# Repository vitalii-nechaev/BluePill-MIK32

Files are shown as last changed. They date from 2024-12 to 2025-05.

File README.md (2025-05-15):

# BluePill-MIK32
Проект отладочной платы MIK32 АМУР К1948ВК018, выполненный в среде KiCad.   
В папке КД находятся pdf-файлы документации на плату. Текстовые документы сгенерированы в программе [ДокГОСТ](https://github.com/vitalii-nechaev/DocGOST).  
Подробнее с проектом можно ознакомиться на [странице проекта](http://xn-----6kccalfmhwcdcrbm1aajnghfrqjce3b0z.xn--p1ai/MCU/MIK32_devboard.html).

BluePill-MIK32

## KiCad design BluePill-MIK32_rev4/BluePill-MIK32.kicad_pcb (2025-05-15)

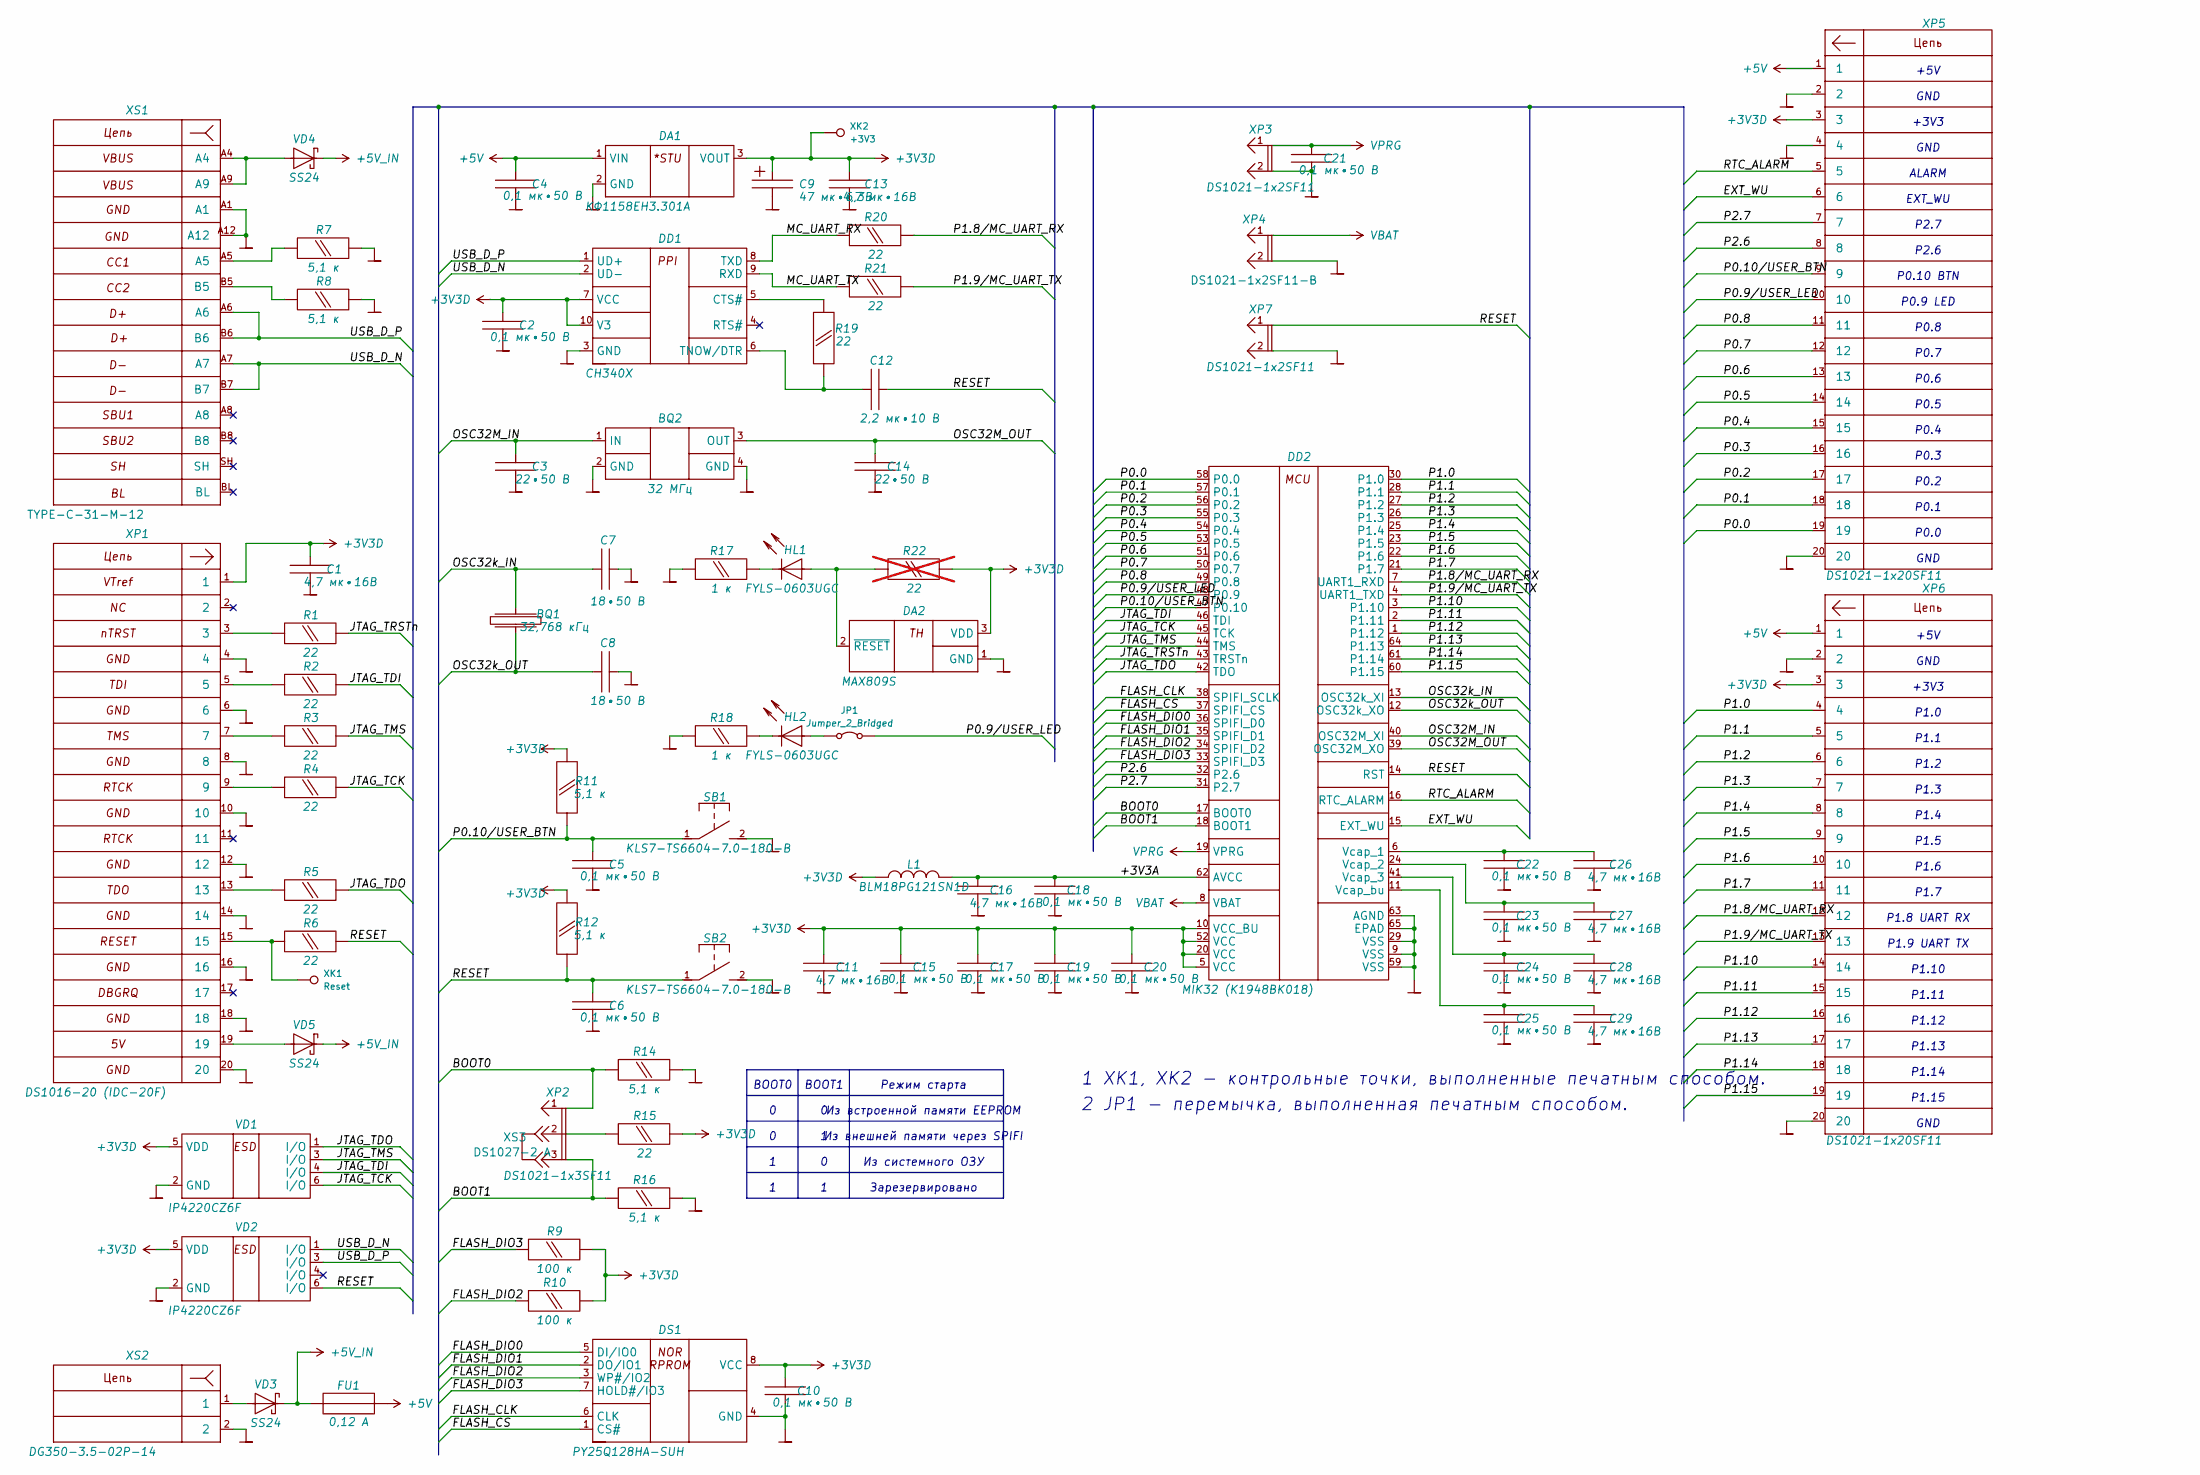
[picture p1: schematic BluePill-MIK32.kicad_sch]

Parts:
BQ1: 32,768 кГц; Crystal_SMD_3215-2Pin_3.2x1.5mm; PartNumber X321532768KGD2SI
BQ2: 32 МГц; Crystal_SMD_3225-4Pin_3.2x2.5mm; PartNumber X322532MOB4SI
C1, C11, C13, C16, C26, C27, C28, C29: 4,7 мк•16В; C_0603_1608Metric; PartNumber GRM188R61C475KE11D
C2, C4, C5, C6, C10, C15, C17, C18, C19, C20, C21, C22, C23, C24, C25: 0,1 мк•50 В; C_0402_1005Metric; PartNumber GRM155R71H104KE14D
C3, C14: 22•50 В; C_0402_1005Metric; PartNumber GRM1555C1H220JA01D
C7, C8: 18•50 В; C_0402_1005Metric; PartNumber GRM1555C1E180JA01D
C9: 47 мк•6,3В; CP_Radial_D5mm_P2.5mm_H11mm; PartNumber К50-68-6,3В-47мкФ±20%
C12: 2,2 мк•10 В; C_0402_1005Metric; PartNumber GRM155R61A225KE01D
DA1: КФ1158ЕН3.301А; TO-252-2; PartNumber КФ1158ЕН3.301А
DA2: MAX809S; SOT-23; PartNumber MAX809S
DD1: CH340X; MSOP-10_3x3mm_P0.5mm; PartNumber CH340X
DD2: MIK32 (К1948ВК018); QFN-64-1EP_8x8mm_P0.4mm_EP6.5x6.5mm; PartNumber К1948ВК018
DS1: PY25Q128HA-SUH; SOIC-8_5.23x5.23mm_P1.27mm; PartNumber PY25Q128HA-SUH
FU1: 0,12 А; Fuse_1206_3216Metric; PartNumber FSMD012-1206-R
HL1, HL2: FYLS-0603UGC; LED_0603_1608Metric; PartNumber FYLS-0603UGC
JP1: Jumper_2_Bridged; SolderJumper-2_P1.3mm_Bridged_RoundedPad1.0x1.5mm
L1: BLM18PG121SN1D; L_0603_1608Metric; PartNumber BLM18PG121SN1D
R1, R2, R3, R4, R5, R6, R15, R19, R20, R21: 22; R_0603_1608Metric; PartNumber RC0603JR-0722RL
R7, R8, R11, R12, R14, R16: 5,1 к; R_0603_1608Metric; PartNumber RC0603FR-075K1L
R9, R10: 100 к; R_0603_1608Metric; PartNumber RC0603JR-07100KL
R17, R18: 1 к; R_0603_1608Metric; PartNumber RC0603JR-071KL
R22: 22; R_0603_1608Metric; PartNumber RC0603JR-0722RL; not fitted
SB1, SB2: KLS7-TS6604-7.0-180-B; SW_Push_1P1T_NO_6x6mm_H9.5mm; PartNumber KLS7-TS6604-7.0-180-B
VD1, VD2: IP4220CZ6F; SOT-23-6; PartNumber IP4220CZ6
VD3, VD4, VD5: SS24; DO-214AC(SMA); PartNumber SS24
XK1: Reset; TestPoint_THTPad_D2.0mm_Drill1.0mm
XK2: +3V3; TestPoint_THTPad_D2.0mm_Drill1.0mm
XP1: DS1016-20 (IDC-20F); IDC-Header_2x10_P2.54mm_Vertical; PartNumber DS1016-20 (IDC-20F)
XP2: DS1021-1x3SF11; PinHeader_1x03_P2.54mm_Vertical; PartNumber DS1021-1x3SF11
XP3, XP7: DS1021-1x2SF11; PinHeader_1x02_P2.54mm_Vertical; PartNumber DS1021-1x2SF11
XP4: DS1021-1x2SF11-B; PinHeader_1x02_P2.54mm_Vertical; PartNumber DS1021-1x2SF11-B
XP5, XP6: DS1021-1x20SF11; PinHeader_1x20_P2.54mm_Vertical; PartNumber DS1021-1x20SF11
XS1: TYPE-C-31-M-12; USB_C_Receptacle_16P_TopMnt_Horizontal; PartNumber TYPE-C-31-M-12
XS2: DG350-3.5-02P-14; TerminalBlock_1x02_P3.50mm_Horizontal; PartNumber DG350-3.5-02P-14
XS3: DS1027-2 A; PartNumber DS1027-2 A

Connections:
+3V3D: C1.1, C2.1, C9.1, C10.1, C11.1, C13.1, C15.1, C17.1, C19.1, C20.1, DA1.3 (VOUT), DA2.3 (VDD), DD1.7 (VCC), DD1.10 (V3), DD2.5 (VCC), DD2.10 (VCC_BU), DD2.20 (VCC), DD2.52 (VCC), DS1.8 (VCC), L1.1, R9.2, R10.2, R11.2, R12.2, R15.2, R22.2, VD1.5 (VDD), VD2.5 (VDD), XK2.1, XP1.1, XP5.3, XP6.3
+5V: C4.1, DA1.1 (VIN), FU1.2, XP5.1, XP6.1
+5V_IN: FU1.1, VD3.1 (K), VD4.1 (K), VD5.1 (K)
/+3V3A: C16.1, C18.1, DD2.62 (AVCC), L1.2
/BOOT0: DD2.17 (BOOT0), R14.1, XP2.1
/BOOT1: DD2.18 (BOOT1), R16.1, XP2.3
/EXT_WU: DD2.15 (EXT_WU), XP5.6
/FLASH_CLK: DD2.38 (SPIFI_SCLK), DS1.6 (CLK)
/FLASH_CS: DD2.37 (SPIFI_CS), DS1.1 (CS#)
/FLASH_DIO0: DD2.36 (SPIFI_D0), DS1.5 (DI/IO0)
/FLASH_DIO1: DD2.35 (SPIFI_D1), DS1.2 (DO/IO1)
/FLASH_DIO2: DD2.34 (SPIFI_D2), DS1.3 (WP#/IO2), R10.1
/FLASH_DIO3: DD2.33 (SPIFI_D3), DS1.7 (HOLD#/IO3), R9.1
/JTAG_TCK: DD2.45 (TCK), R4.2, VD1.6 (I/O)
/JTAG_TDI: DD2.46 (TDI), R2.2, VD1.4 (I/O)
/JTAG_TDO: DD2.42 (TDO), R5.2, VD1.1 (I/O)
/JTAG_TMS: DD2.44 (TMS), R3.2, VD1.3 (I/O)
/JTAG_TRSTn: DD2.43 (TRSTn), R1.2
/MC_UART_RX: DD1.8 (TXD), R20.1
/MC_UART_TX: DD1.9 (RXD), R21.1
/OSC32M_IN: BQ2.1 (IN), C3.1, DD2.40 (OSC32M_XI)
/OSC32M_OUT: BQ2.3 (OUT), C14.1, DD2.39 (OSC32M_XO)
/OSC32k_IN: BQ1.2, C7.1, DD2.13 (OSC32k_XI)
/OSC32k_OUT: BQ1.1, C8.1, DD2.12 (OSC32k_XO)
/P0.0: DD2.58 (P0.0), XP5.19
/P0.1: DD2.57 (P0.1), XP5.18
/P0.2: DD2.56 (P0.2), XP5.17
/P0.3: DD2.55 (P0.3), XP5.16
/P0.4: DD2.54 (P0.4), XP5.15
/P0.5: DD2.53 (P0.5), XP5.14
/P0.6: DD2.51 (P0.6), XP5.13
/P0.7: DD2.50 (P0.7), XP5.12
/P0.8: DD2.49 (P0.8), XP5.11
/P0.9/USER_LED: DD2.48 (P0.9), JP1.2 (B), XP5.10
/P0.10/USER_BTN: C5.1, DD2.47 (P0.10), R11.1, SB1.1, XP5.9
/P1.0: DD2.30 (P1.0), XP6.4
/P1.1: DD2.28 (P1.1), XP6.5
/P1.2: DD2.27 (P1.2), XP6.6
/P1.3: DD2.26 (P1.3), XP6.7
/P1.4: DD2.25 (P1.4), XP6.8
/P1.5: DD2.23 (P1.5), XP6.9
/P1.6: DD2.22 (P1.6), XP6.10
/P1.7: DD2.21 (P1.7), XP6.11
/P1.8/MC_UART_RX: DD2.7 (UART1_RXD), R20.2, XP6.12
/P1.9/MC_UART_TX: DD2.4 (UART1_TXD), R21.2, XP6.13
/P1.10: DD2.3 (P1.10), XP6.14
/P1.11: DD2.2 (P1.11), XP6.15
/P1.12: DD2.1 (P1.12), XP6.16
/P1.13: DD2.64 (P1.13), XP6.17
/P1.14: DD2.61 (P1.14), XP6.18
/P1.15: DD2.60 (P1.15), XP6.19
/P2.6: DD2.32 (P2.6), XP5.8
/P2.7: DD2.31 (P2.7), XP5.7
/RESET: C6.1, C12.2, DD2.14 (RST), R6.2, R12.1, SB2.1, VD2.6 (I/O), XP7.1
/RTC_ALARM: DD2.16 (RTC_ALARM), XP5.5
/USB_D_N: DD1.2 (UD-), VD2.1 (I/O), XS1.A7, XS1.B7
/USB_D_P: DD1.1 (UD+), VD2.3 (I/O), XS1.A6, XS1.B6
GND: BQ2.2 (GND), BQ2.4 (GND), C1.2, C2.2, C3.2, C4.2, C5.2, C6.2, C7.2, C8.2, C9.2, C10.2, C11.2, C13.2, C14.2, C15.2, C16.2, C17.2, C18.2, C19.2, C20.2, C21.2, C22.2, C23.2, C24.2, C25.2, C26.2, C27.2, C28.2, C29.2, DA1.2 (GND), DA2.1 (GND), DD1.3 (GND), DD2.9 (VSS), DD2.29 (VSS), DD2.59 (VSS), DD2.63 (AGND), DD2.65 (EPAD), DS1.4 (GND), R7.2, R8.2, R14.2, R16.2, R17.1, R18.1, SB1.2, SB2.2, VD1.2 (GND), VD2.2 (GND), XP1.4, XP1.6, XP1.8, XP1.10, XP1.12, XP1.14, XP1.16, XP1.18, XP1.20, XP3.2, XP4.2, XP5.2, XP5.4, XP5.20, XP6.2, XP6.20, XP7.2, XS1.A1, XS1.A12, XS2.2
unnamed: DA2.2 (~RESET), HL1.2 (A), R22.1
unnamed: DD1.5 (CTS#), R19.2
unnamed: C12.1, DD1.6 (TNOW/DTR), R19.1
unnamed: C22.1, C26.1, DD2.6 (Vcap_1)
unnamed: C23.1, C27.1, DD2.24 (Vcap_2)
unnamed: C24.1, C28.1, DD2.41 (Vcap_3)
unnamed: C25.1, C29.1, DD2.11 (Vcap_bu)
unnamed: HL1.1 (K), R17.2
unnamed: HL2.2 (A), JP1.1 (A)
unnamed: HL2.1 (K), R18.2
unnamed: R1.1, XP1.3
unnamed: R2.1, XP1.5
unnamed: R3.1, XP1.7
unnamed: R4.1, XP1.9
unnamed: R5.1, XP1.13
unnamed: R6.1, XK1.1, XP1.15
unnamed: R7.1, XS1.A5
unnamed: R8.1, XS1.B5
unnamed: R15.1, XP2.2
unnamed: VD3.2 (A), XS2.1
unnamed: VD4.2 (A), XS1.A4, XS1.A9
unnamed: VD5.2 (A), XP1.19
VBAT: DD2.8 (VBAT), XP4.1
VPRG: C21.1, DD2.19 (VPRG), XP3.1

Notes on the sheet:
P1.0
+5V
P1.2
GND
EXT_WU
BOOT1
Режим старта
P1.5
P1.8 UART RX
2 JP1 - перемычка, выполненная печатным способом.
P0.1
P1.1
Из системного ОЗУ
P1.11
P1.15
P1.6
P1.7
P0.2
P1.9 UART TX
Из внешней памяти через SPIFI
P0.10 BTN
P0.4
P1.14
ALARM
P2.6
P0.7
1 XK1, XK2 - контрольные точки, выполненные печатным способом.
P2.7
P1.12
P1.10
Зарезервировано
P0.9 LED
P0.8
P0.0
P0.5
BOOT0
Из встроенной памяти EEPROM
P1.13
P0.3
P1.4

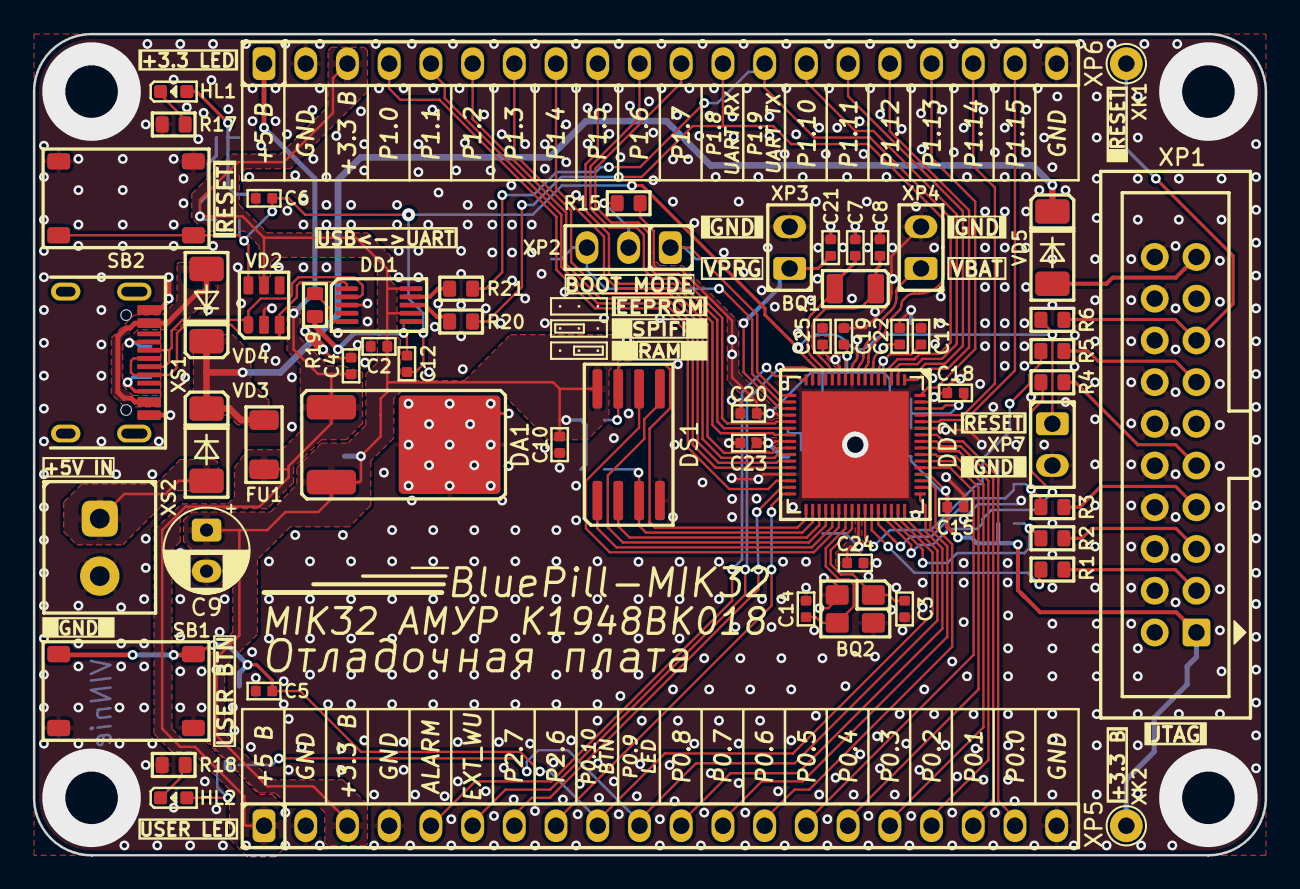
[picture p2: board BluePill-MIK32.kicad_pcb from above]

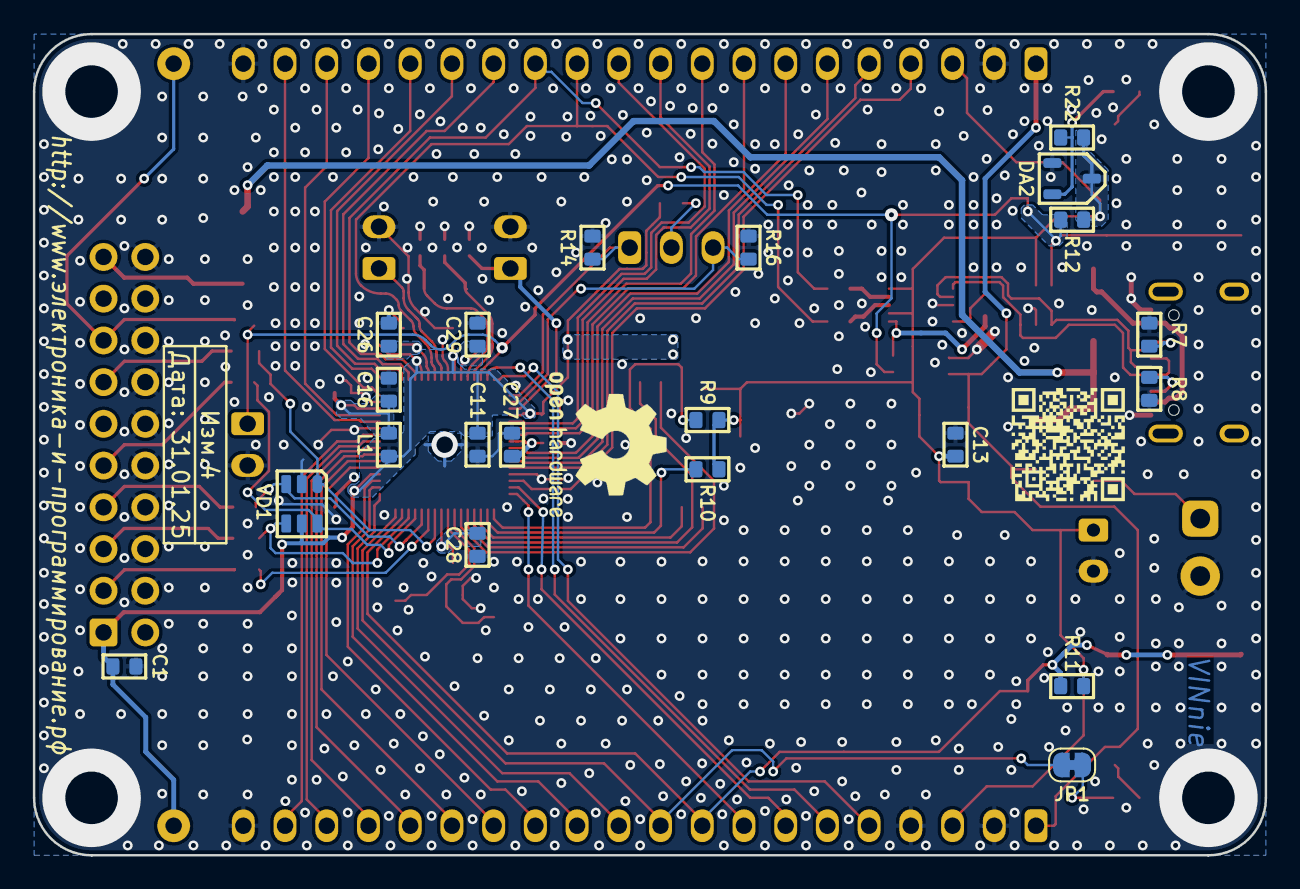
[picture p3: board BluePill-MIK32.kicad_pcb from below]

Board: 2 copper layers, 75.0 x 50.0 mm, 80 parts (21 on the bottom side), 82 nets.
